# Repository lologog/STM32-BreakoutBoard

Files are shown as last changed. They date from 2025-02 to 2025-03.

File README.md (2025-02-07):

# STM32 Breakout Board

A minimalist development board for STM32, allowing easy connection to the microcontroller and testing its capabilities.

## Project Description
This board is designed for prototyping with STM32 microcontrollers. It enables easy access to processor pins and testing its functions without requiring ready-made kits such as Nucleo or Discovery. The project includes:

- **Microcontroller:** STM32L476RGT6
- **Power Supply:** 5V (barrel connector)
- **Programming:** STLINK-V3MINIE
- **LED Indicators:** Red LED indicating power supply
- **Easy access to GPIO pins**

---

## PCB Rendering
Below is a 3D render generated in KiCad:

<div align="center">
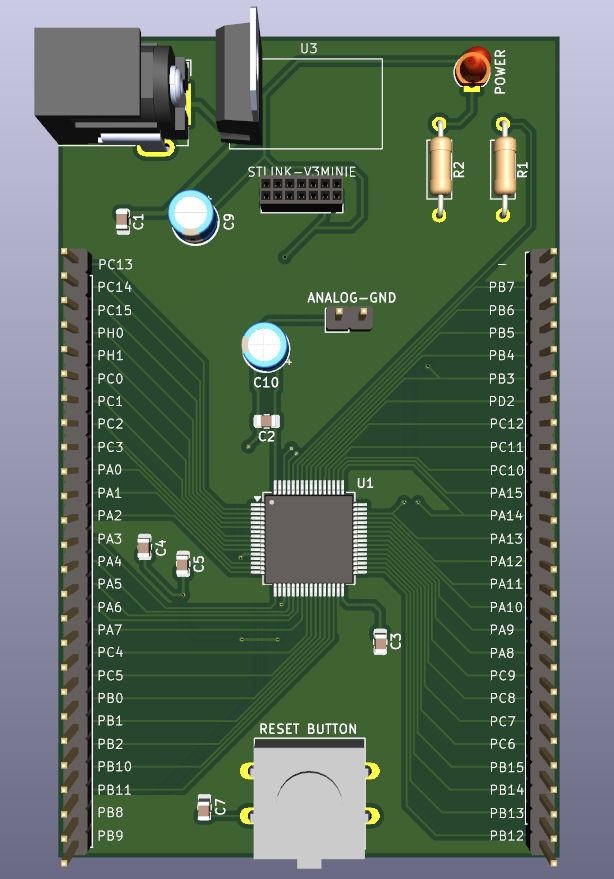
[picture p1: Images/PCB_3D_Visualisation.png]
3D View
    
</div>

---

## Real-World Implementation
This is the completed PCB:

<div align="center">
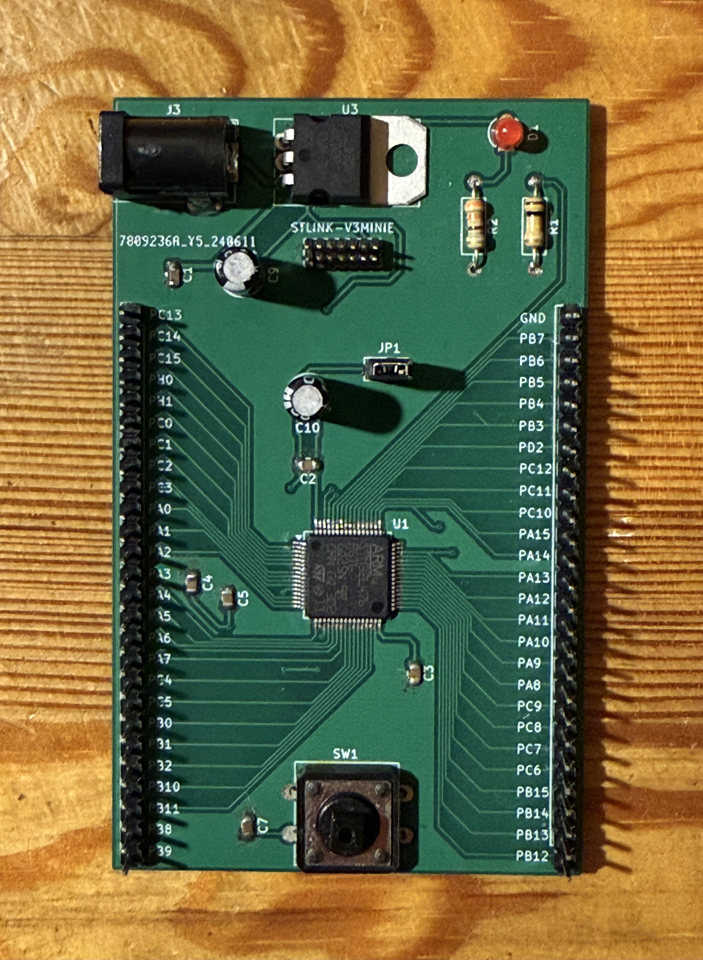
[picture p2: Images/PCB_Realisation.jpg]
Real PCB
    
</div>

---

## Presentation
Below is an animated preview of the board in action:

<div align="center">
    Demo GIF
</div>

---

## Usage Instructions
1. Connect a 5V power supply to the barrel connector.
2. Connect the **STLINK-V3MINIE** programmer.
3. Upload test firmware.
4. Test GPIO pin functionality and develop your applications.

## Author
- **Name**: Krzysztof Tomicki
- **Contact**: tomicki.krzysztof.pv@gmail.com

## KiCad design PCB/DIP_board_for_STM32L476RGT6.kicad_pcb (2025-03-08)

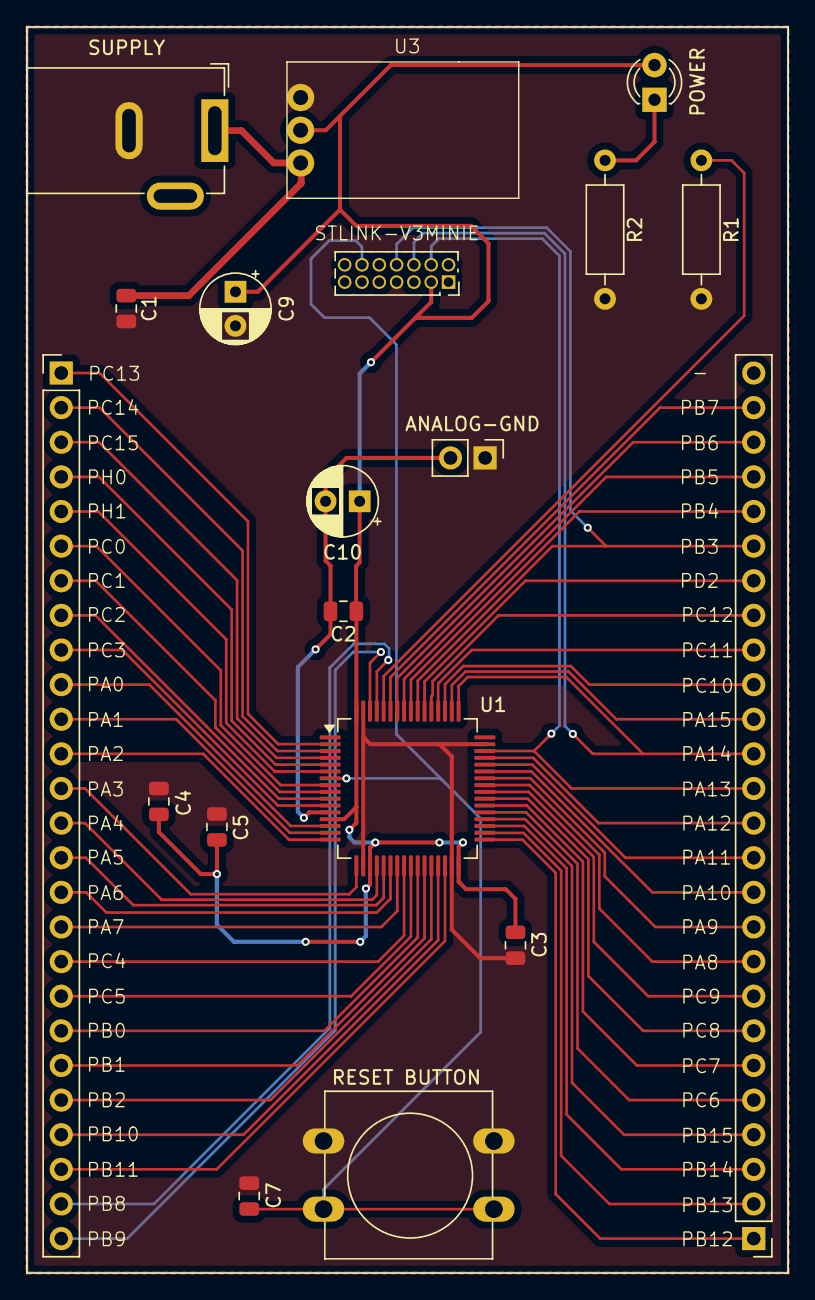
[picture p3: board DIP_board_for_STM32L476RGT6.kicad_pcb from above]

Board: 2 copper layers, 55.7 x 91.3 mm, 19 parts (0 on the bottom side), 58 nets.

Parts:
ANALOG-GND: Jumper_2_Bridged; PinHeader_1x02_P2.54mm_Vertical
C1, C2, C3, C4, C5, C7: 100n; C_0805_2012Metric
C9, C10: 10u; CP_Radial_D5.0mm_P2.50mm
IDP-14pin-1.27-port1: PinSocket_2x07_P1.27mm_Vertical
J1, J2: Conn_01x26_Pin; PinHeader_1x26_P2.54mm_Vertical
POWER: SUPP_LED; LED_D3.0mm
R1: 100k; R_Axial_DIN0207_L6.3mm_D2.5mm_P10.16mm_Horizontal
R2: 330; R_Axial_DIN0207_L6.3mm_D2.5mm_P10.16mm_Horizontal
RESET BUTTON: SW_Push; SW_PUSH-12mm
SUPPLY: Barrel_Jack_Switch_Pin3Ring; BarrelJack_GCT_DCJ200-10-A_Horizontal
U1: STM32L476RGTx; LQFP-64_10x10mm_P0.5mm
U3: LD1117S33TR_SOT223; LD1117V33 - tht

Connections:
3V3: C2.1, C3.1, C4.1, C5.1, C9.1, C10.1, IDP-14pin-1.27-port1.3 (VCC), POWER.2 (A), U1.13 (VDDA), U1.19 (VDD), U1.32 (VDD), U1.64 (VDD), U3.2 (VO)
+5V: C1.1, SUPPLY.1, U3.3 (VI)
GND: ANALOG-GND.1 (A), C1.2, C3.2, C4.2, C5.2, C7.2, C9.2, IDP-14pin-1.27-port1.7 (GND), R1.2, R2.2, RESET BUTTON.1, SUPPLY.3, U1.18 (VSS), U1.31 (VSS), U1.47 (VSS), U1.63 (VSS), U3.1 (GND)
GND1: ANALOG-GND.2 (B), C2.2, C10.2, U1.12 (VSSA)
NRST: C7.1, IDP-14pin-1.27-port1.12 (RESET), RESET BUTTON.2, U1.7 (NRST)
unnamed: POWER.1 (K), R2.1
unnamed: R1.1, U1.60 (BOOT0)
PA0: J1.10, U1.14 (PA0)
PA1: J1.11, U1.15 (PA1)
PA2: J1.12, U1.16 (PA2)
PA3: J1.13, U1.17 (PA3)
PA4: J1.14, U1.20 (PA4)
PA5: J1.15, U1.21 (PA5)
PA6: J1.16, U1.22 (PA6)
PA7: J1.17, U1.23 (PA7)
PA8: J2.9, U1.41 (PA8)
PA9: J2.10, U1.42 (PA9)
PA10: J2.11, U1.43 (PA10)
PA11: J2.12, U1.44 (PA11)
PA12: J2.13, U1.45 (PA12)
PA13: IDP-14pin-1.27-port1.4 (SWDIO), J2.14, U1.46 (PA13)
PA14: IDP-14pin-1.27-port1.6 (SWCLK), J2.15, U1.49 (PA14)
PA15: J2.16, U1.50 (PA15)
PB0: J1.20, U1.26 (PB0)
PB1: J1.21, U1.27 (PB1)
PB2: J1.22, U1.28 (PB2)
PB3: IDP-14pin-1.27-port1.8 (SWO), J2.21, U1.55 (PB3)
PB4: J2.22, U1.56 (PB4)
PB5: J2.23, U1.57 (PB5)
PB6: J2.24, U1.58 (PB6)
PB7: J2.25, U1.59 (PB7)
PB8: J1.25, U1.61 (PB8)
PB9: J1.26, U1.62 (PB9)
PB10: J1.23, U1.29 (PB10)
PB11: J1.24, U1.30 (PB11)
PB12: J2.1, U1.33 (PB12)
PB13: J2.2, U1.34 (PB13)
PB14: J2.3, U1.35 (PB14)
PB15: J2.4, U1.36 (PB15)
PC0: J1.6, U1.8 (PC0)
PC1: J1.7, U1.9 (PC1)
PC2: J1.8, U1.10 (PC2)
PC3: J1.9, U1.11 (PC3)
PC4: J1.18, U1.24 (PC4)
PC5: J1.19, U1.25 (PC5)
PC6: J2.5, U1.37 (PC6)
PC7: J2.6, U1.38 (PC7)
PC8: J2.7, U1.39 (PC8)
PC9: J2.8, U1.40 (PC9)
PC10: J2.17, U1.51 (PC10)
PC11: J2.18, U1.52 (PC11)
PC12: J2.19, U1.53 (PC12)
PC13: J1.1, U1.2 (PC13)
PC14: J1.2, U1.3 (PC14)
PC15: J1.3, U1.4 (PC15)
PD2: J2.20, U1.54 (PD2)
PH0: J1.4, U1.5 (PH0)
PH1: J1.5, U1.6 (PH1)

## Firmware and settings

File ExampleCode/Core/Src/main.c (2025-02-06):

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
/* Includes ------------------------------------------------------------------*/
#include "main.h"

/* USER CODE BEGIN PD */
#define CENTER (3)
/* USER CODE END PD */


void SystemClock_Config(void);
static void MX_GPIO_Init(void);
/* USER CODE BEGIN 0 */
GPIO_TypeDef* LED_PORTS[] = {LD1_GPIO_Port,
							 LD2_GPIO_Port,
							 LD3_GPIO_Port,
							 LD4_GPIO_Port,
							 LD5_GPIO_Port,
							 LD6_GPIO_Port,
							 LD7_GPIO_Port};

uint16_t LED_PINS[] = {LD1_Pin,
					   LD2_Pin,
					   LD3_Pin,
					   LD4_Pin,
					   LD5_Pin,
					   LD6_Pin,
					   LD7_Pin};
/* USER CODE END 0 */

/**
  * @brief  The application entry point.
  * @retval int
  */
int main(void)
{

  /* MCU Configuration--------------------------------------------------------*/

  /* Reset of all peripherals, Initializes the Flash interface and the Systick. */
  HAL_Init();

  /* Configure the system clock */
  SystemClock_Config();

  /* Initialize all configured peripherals */
  MX_GPIO_Init();
  /* Infinite loop */
  /* USER CODE BEGIN WHILE */
  while (1)
  {
	  for (int8_t i = 0; i <= CENTER; i++)
	  {
		  HAL_Delay(100); // using HAL_DELAY only for demonstration
		  HAL_GPIO_WritePin(LED_PORTS[CENTER - i], LED_PINS[CENTER - i], GPIO_PIN_SET);
		  HAL_GPIO_WritePin(LED_PORTS[CENTER + i], LED_PINS[CENTER + i], GPIO_PIN_SET);
	  }

	  for (int8_t i = CENTER; i >= 0; i--)
	  {
		  HAL_Delay(100);
		  HAL_GPIO_WritePin(LED_PORTS[CENTER - i], LED_PINS[CENTER - i], GPIO_PIN_RESET);
		  HAL_GPIO_WritePin(LED_PORTS[CENTER + i], LED_PINS[CENTER + i], GPIO_PIN_RESET);
	  }
    /* USER CODE END WHILE */

    /* USER CODE BEGIN 3 */
  }
  /* USER CODE END 3 */
}

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


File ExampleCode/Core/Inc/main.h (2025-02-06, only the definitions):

#define LD1_Pin GPIO_PIN_12
#define LD1_GPIO_Port GPIOB
#define LD2_Pin GPIO_PIN_13
#define LD2_GPIO_Port GPIOB
#define LD3_Pin GPIO_PIN_14
#define LD3_GPIO_Port GPIOB
#define LD4_Pin GPIO_PIN_15
#define LD4_GPIO_Port GPIOB
#define LD5_Pin GPIO_PIN_6
#define LD5_GPIO_Port GPIOC
#define LD6_Pin GPIO_PIN_7
#define LD6_GPIO_Port GPIOC
#define LD7_Pin GPIO_PIN_8
#define LD7_GPIO_Port GPIOC

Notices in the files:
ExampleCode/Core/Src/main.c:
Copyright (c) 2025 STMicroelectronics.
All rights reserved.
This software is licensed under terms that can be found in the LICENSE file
